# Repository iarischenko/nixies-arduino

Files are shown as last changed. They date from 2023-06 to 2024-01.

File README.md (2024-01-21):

# nixies-arduino
The repository contains sch, pcb and source code files for clock based on
IN12 nixie tubes.
The clock is based on custom stm32 board, MAX1771 boost converter, HV5812 high
voltage drivers, PEC16 encoder and FUSB302 usb pd phy.

## folder structure
freecad-project: case FreeCAD 3d models\
kicad-projects : pcb's KiCAD projects\
software       : libopencm3 based software for stm32 based MCU board

## IN12 v3
(master)
in12 nixie tubes (https://youtu.be/ojTo4SyceIE)

## IN12 v2
see v2 tag
### IN12 v2 (demo, clickable video)
in12 nixie tubes (http://www.youtube.com/watch?v=4i1YHq5AIks)

## IN12 v1
see v1 tag
Prototype photo:


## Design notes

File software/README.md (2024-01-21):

Easy "clone and go" repository for a libopencm3 based project.

# Instructions
 1. git clone --recurse-submodules https://github.com/libopencm3/libopencm3-template.git your-project
 2. cd software
 3. make -C libopencm3 # (Only needed once)
 4. bear --append -- make -C stm32f103-nixie

bear is needed to create compile_commands.json and enable clangd

If you have an older git, or got ahead of yourself and skipped the ```--recurse-submodules```
you can fix things by running ```git submodule update --init``` (This is only needed once)

# Directories
* stm32f103-nixie contains stm32 nixie tubes application

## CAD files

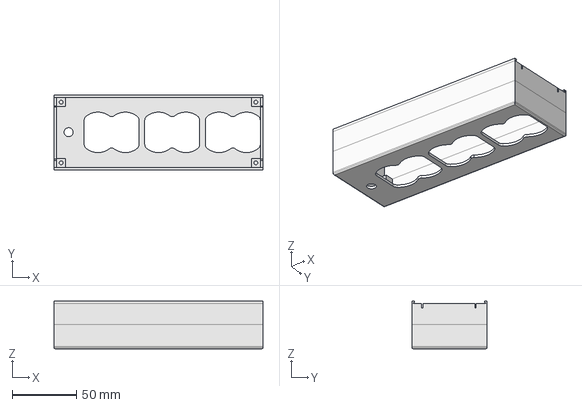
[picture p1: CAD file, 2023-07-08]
freecad-project/case2-Body.step
162.2 x 58.2 x 37.0 mm

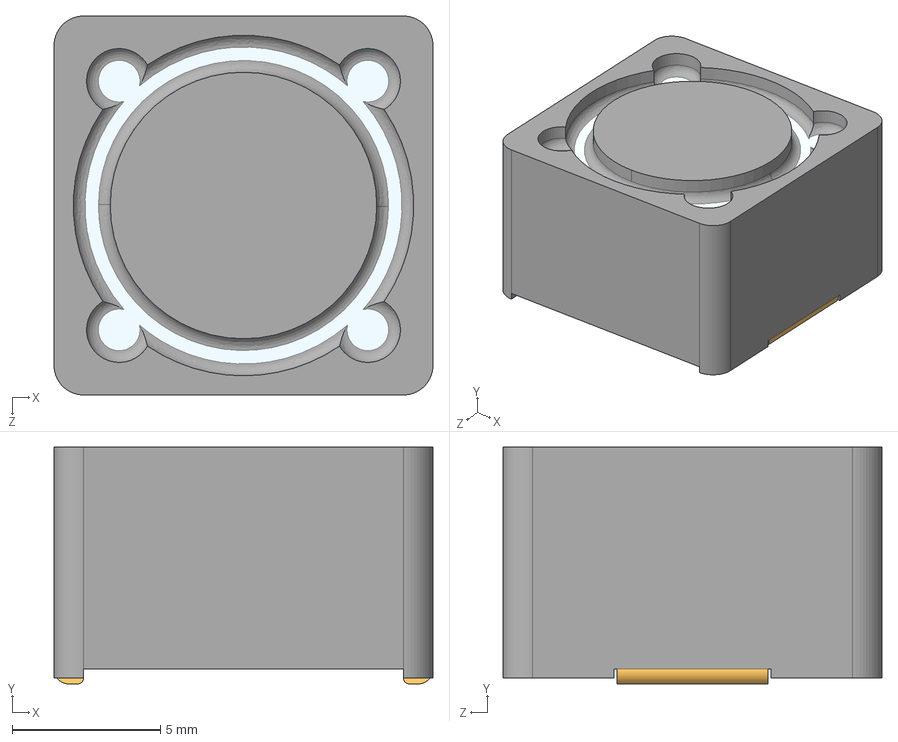
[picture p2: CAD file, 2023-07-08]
kicad-projects/3d_model/User Library-b82477g4.step
12.8 x 8.00 x 12.8 mm

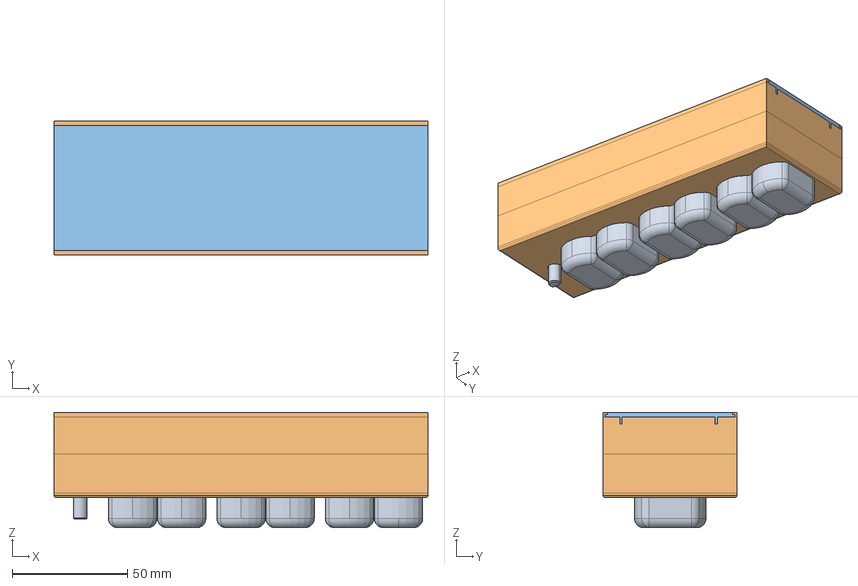
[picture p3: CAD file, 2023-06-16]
freecad-project/case2.FCStd
162.2 x 58.2 x 50.0 mm
clock_top

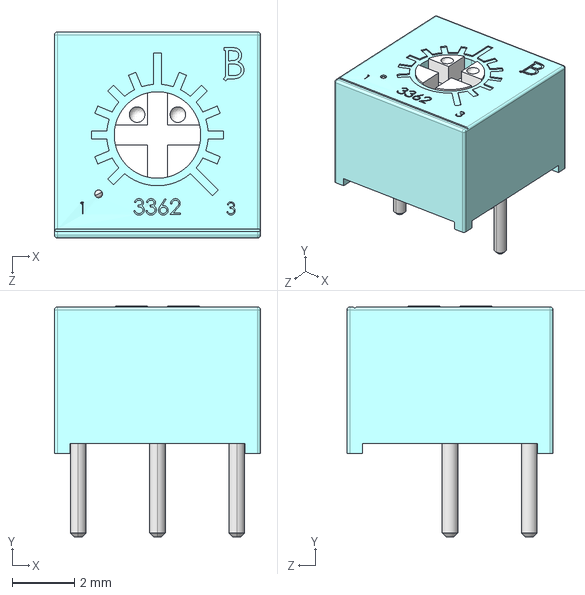
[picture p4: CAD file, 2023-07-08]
kicad-projects/3d_model/User Library-3362P-1-102LF.step
6.60 x 7.40 x 6.60 mm

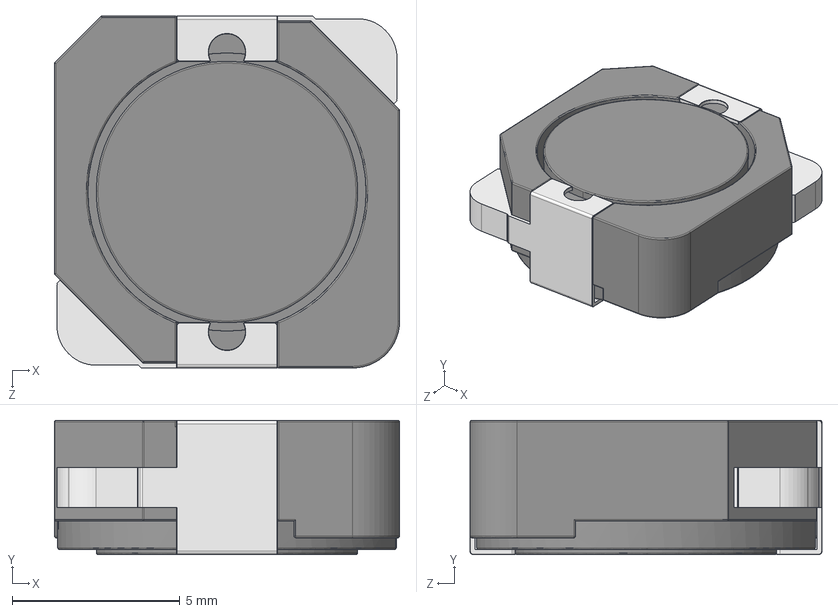
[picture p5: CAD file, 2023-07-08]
kicad-projects/3d_model/User Library-cdrh104r.STEP
10.3 x 4.00 x 10.5 mm
CDRH104R_KORPUS
CDRH104R_NOGKA
CDRH104R_NOGKA_1

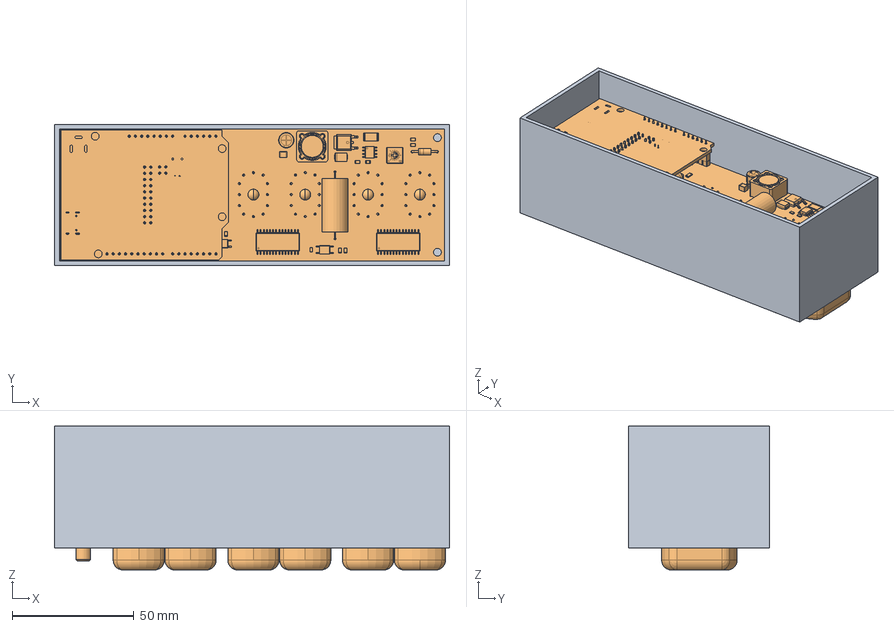
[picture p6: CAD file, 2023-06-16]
freecad-project/case1.FCStd
162.0 x 58.0 x 59.0 mm
clock_top

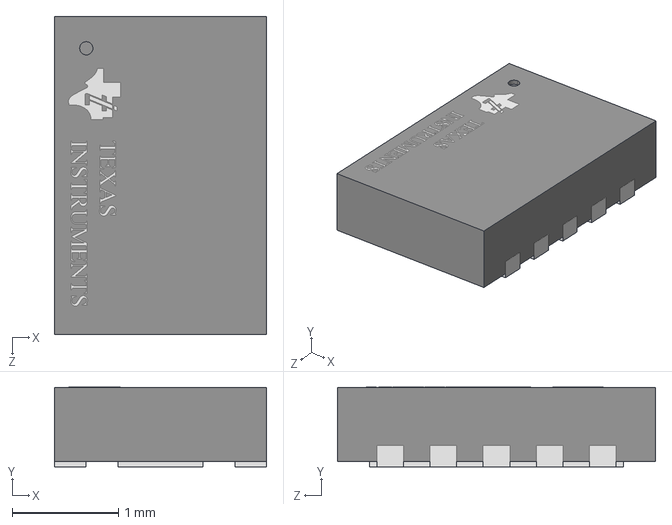
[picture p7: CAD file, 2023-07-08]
kicad-projects/3d_model/User Library-TPS62177DQCT.step
2.00 x 0.75 x 3.00 mm

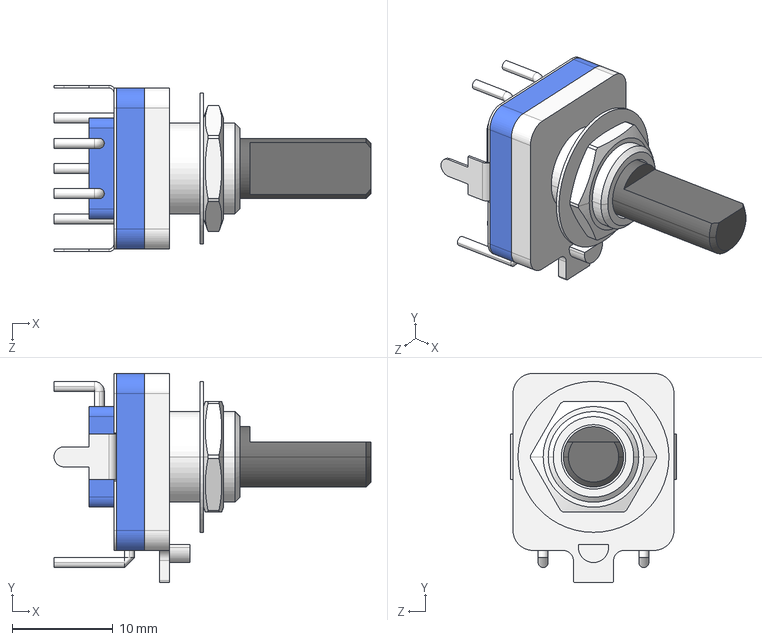
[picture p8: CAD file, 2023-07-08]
kicad-projects/3d_model/User Library-Encoder PEC16-4220F-S0024 BOURNS.step
31.5 x 20.8 x 16.5 mm

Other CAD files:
freecad-project/assemble.FCStd
freecad-project/case2-Body.stl

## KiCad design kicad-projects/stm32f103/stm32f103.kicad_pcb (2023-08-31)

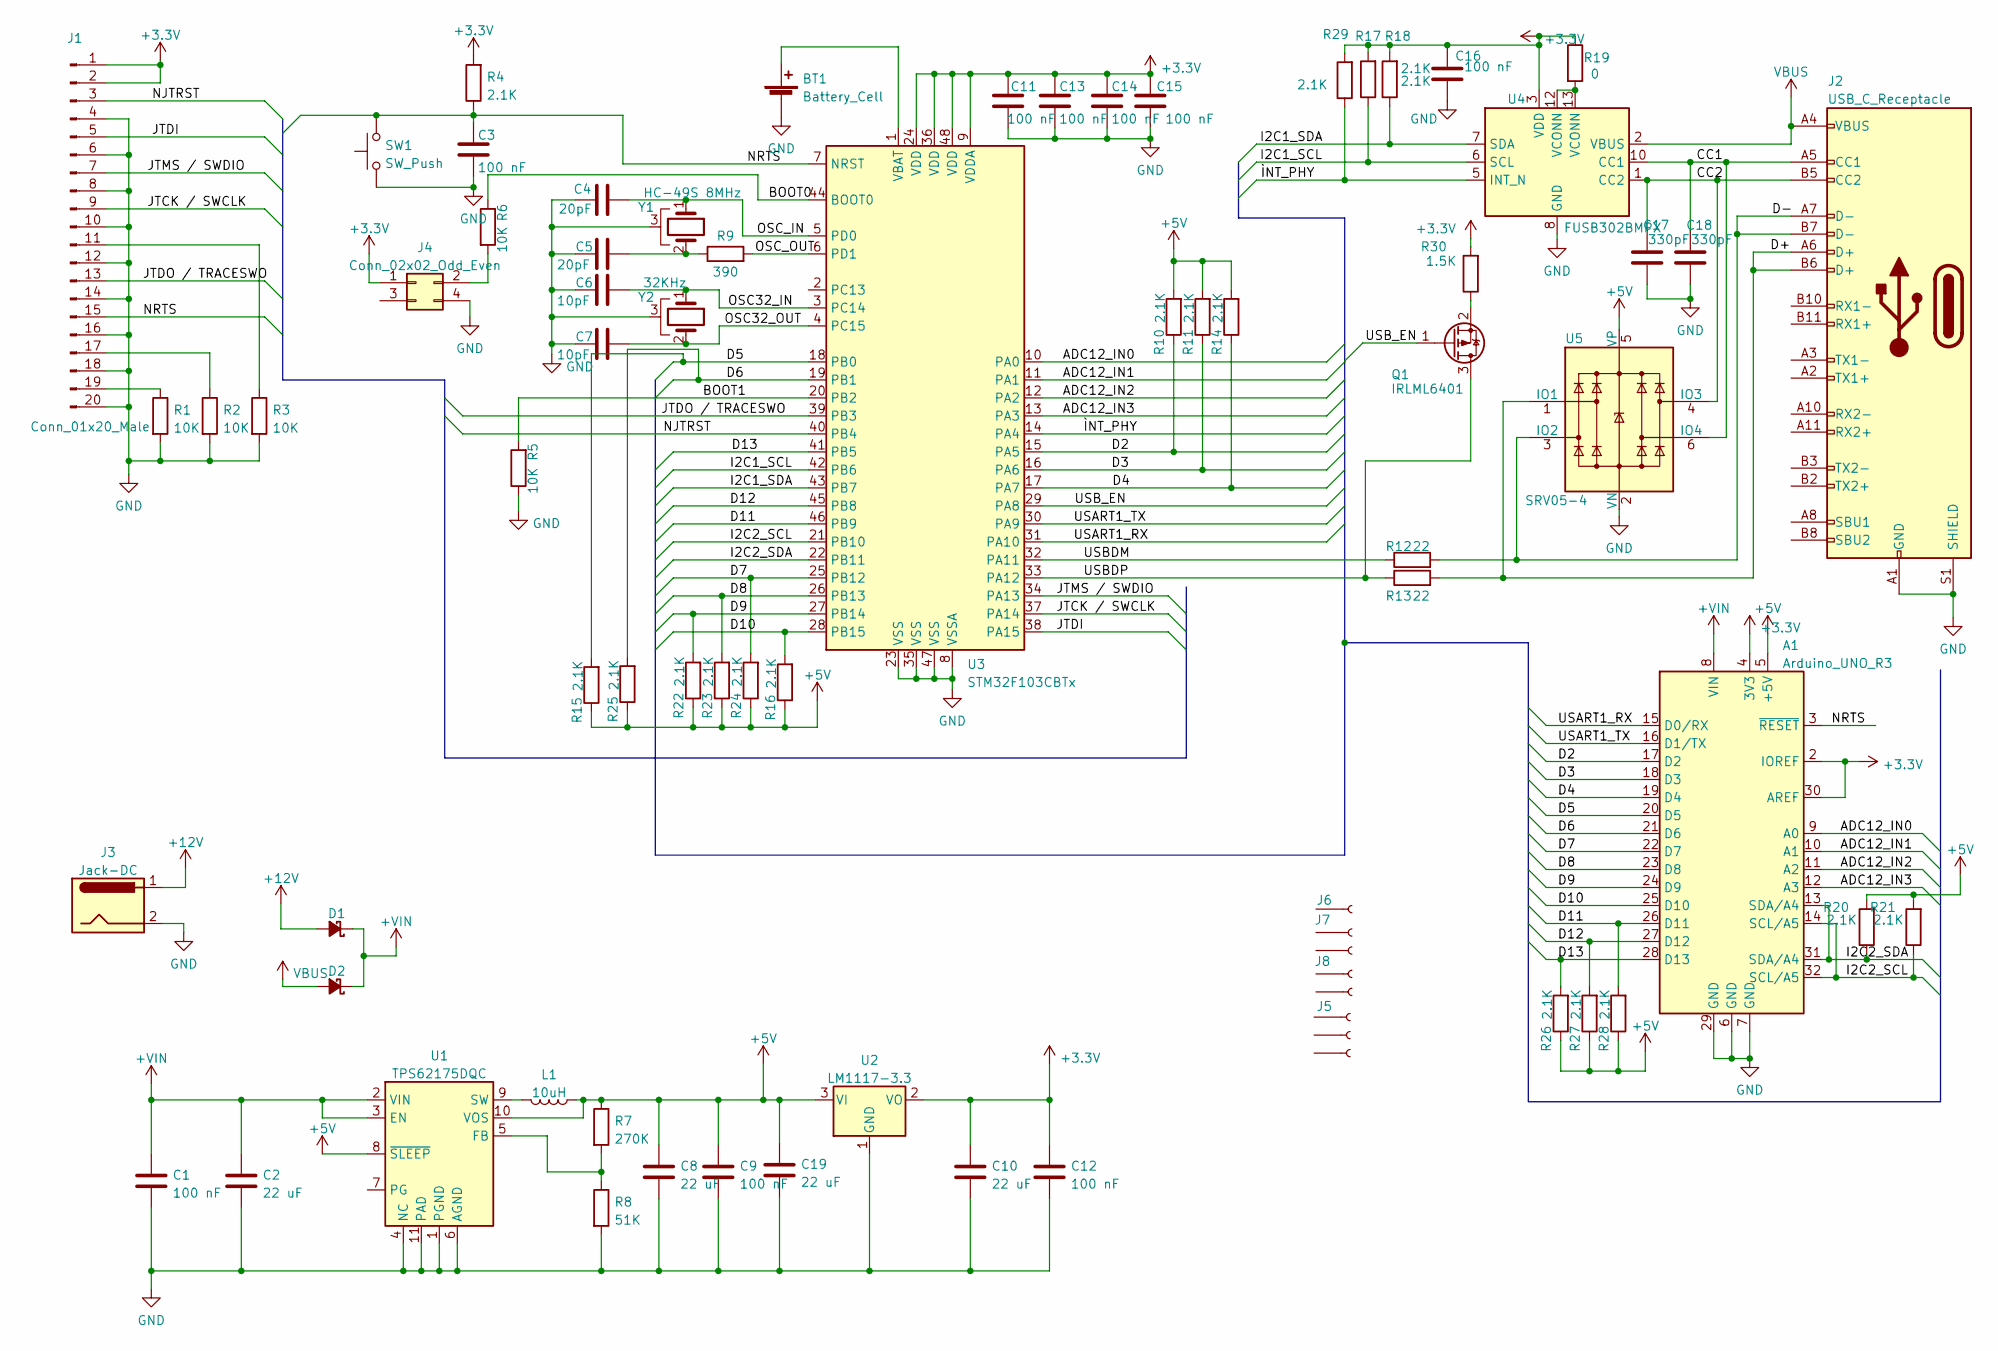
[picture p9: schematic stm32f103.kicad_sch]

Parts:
A1: Arduino_UNO_R3; Arduino_UNO_R3_WithMountingHoles_inverted
BT1: Battery_Cell; BatteryHolder_Keystone_1060_1x2032
C1, C3, C9, C11, C12, C13, C14, C15, C16: 100 nF; C_0805_2012Metric_Pad1.18x1.45mm_HandSolder
C2, C8, C10, C19: 22 uF; C_1206_3216Metric_Pad1.33x1.80mm_HandSolder
C4, C5: 20pF; C_0805_2012Metric_Pad1.18x1.45mm_HandSolder
C6, C7: 10pF; C_0805_2012Metric_Pad1.18x1.45mm_HandSolder
C17, C18: 330pF; C_0805_2012Metric_Pad1.18x1.45mm_HandSolder
D1, D2: D_Schottky_Small_Filled; D_SMA
J1: Conn_01x20_Male; PinHeader_2x10_P2.54mm_Vertical
J2: USB_C_Receptacle; USB_C_Receptacle_HRO_TYPE-C-31-M-12
J3: Jack-DC; BarrelJack_Horizontal
J4: Conn_02x02_Odd_Even; PinHeader_2x02_P2.54mm_Vertical
J5: Conn_01x10_Female; PinSocket_1x10_P2.54mm_Vertical
J6: Conn_01x06_Female; PinSocket_1x06_P2.54mm_Vertical
J7, J8: Conn_01x08_Female; PinSocket_1x08_P2.54mm_Vertical
L1: 10uH; L_Vishay_IHLP-4040
Q1: IRLML6401; SOT-23
R1, R2, R3, R5, R6: 10K; R_0805_2012Metric_Pad1.20x1.40mm_HandSolder
R4, R10, R11, R14, R15, R16, R17, R18, R20, R21, R22, R23, R24, R25, R26, R27, R28, R29: 2.1K; R_0805_2012Metric_Pad1.20x1.40mm_HandSolder
R7: 270K; R_0805_2012Metric_Pad1.20x1.40mm_HandSolder
R8: 51K; R_0805_2012Metric_Pad1.20x1.40mm_HandSolder
R9: 390; R_0805_2012Metric_Pad1.20x1.40mm_HandSolder
R12, R13: 22; R_0805_2012Metric_Pad1.20x1.40mm_HandSolder
R19: 0; R_0805_2012Metric_Pad1.20x1.40mm_HandSolder
R30: 1.5K; R_0805_2012Metric_Pad1.20x1.40mm_HandSolder
SW1: SW_Push; SW_Push_1P1T_NO_CK_KSC7xxJ
U1: TPS62175DQC; WSON-10-1EP_2x3mm_P0.5mm_EP0.84x2.4mm_ThermalVias
U2: LM1117-3.3; SOT-223-3_TabPin2
U3: STM32F103CBTx; LQFP-48_7x7mm_P0.5mm
U4: FUSB302BMPX; WQFN-14-1EP_2.5x2.5mm_P0.5mm_EP1.45x1.45mm
U5: SRV05-4; SOT-23-6
Y1: HC-49S 8MHz; Crystal_SMD_HC49-SD
Y2: 32KHz; Crystal_C38-LF_D3.0mm_L8.0mm_Horizontal_1EP_style2

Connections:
+3.3V: A1.2 (IOREF), A1.4 (3V3), A1.30 (AREF), C10.1, C11.1, C12.1, C13.1, C14.1, C15.1, C16.1, J1.1, J1.2, J4.1, R4.2, R17.2, R18.2, R19.1, R29.2, R30.2, U2.2 (VO), U3.9 (VDDA), U3.24 (VDD), U3.36 (VDD), U3.48 (VDD), U4.3 (VDD), U4.4 (VDD)
+5V: A1.5 (+5V), C8.1, C9.1, C19.1, L1.1, R7.1, R10.2, R11.2, R14.2, R15.1, R16.1, R20.2, R21.2, R22.1, R23.1, R24.1, R25.1, R26.1, R27.1, R28.1, U1.8 (~SLEEP), U1.10 (VOS), U2.3 (VI), U5.5 (VP)
+12V: D1.2 (A), J3.1
+VIN: A1.8 (VIN), C1.1, C2.1, D1.1 (K), D2.1 (K), U1.2 (VIN), U1.3 (EN)
/ADC12_IN0: A1.9 (A0), U3.10 (PA0)
/ADC12_IN1: A1.10 (A1), U3.11 (PA1)
/ADC12_IN2: A1.11 (A2), U3.12 (PA2)
/ADC12_IN3: A1.12 (A3), U3.13 (PA3)
/BOOT0: R6.1, U3.44 (BOOT0)
/BOOT1: R5.2, U3.20 (PB2)
/CC1: C18.2, J2.A5 (CC1), U4.10 (CC1), U4.11 (CC1), U5.6 (IO4)
/CC2: C17.2, J2.B5 (CC2), U4.1 (CC2), U4.14 (CC2), U5.4 (IO3)
/D2: A1.17 (D2), R10.1, U3.15 (PA5)
/D3: A1.18 (D3), R11.1, U3.16 (PA6)
/D4: A1.19 (D4), R14.1, U3.17 (PA7)
/D5: A1.20 (D5), R15.2, U3.18 (PB0)
/D6: A1.21 (D6), R25.2, U3.19 (PB1)
/D7: A1.22 (D7), R24.2, U3.25 (PB12)
/D8: A1.23 (D8), R23.2, U3.26 (PB13)
/D9: A1.24 (D9), R22.2, U3.27 (PB14)
/D10: A1.25 (D10), R16.2, U3.28 (PB15)
/D11: A1.26 (D11), R28.2, U3.46 (PB9)
/D12: A1.27 (D12), R27.2, U3.45 (PB8)
/D13: A1.28 (D13), R26.2, U3.41 (PB5)
/D+: J2.A6 (D+), J2.B6 (D+), R13.2, U5.1 (IO1)
/D-: J2.A7 (D-), J2.B7 (D-), R12.2, U5.3 (IO2)
/I2C1_SCL: R17.1, U3.42 (PB6), U4.6 (SCL)
/I2C1_SDA: R18.1, U3.43 (PB7), U4.7 (SDA)
/I2C2_SCL: A1.14 (SCL/A5), A1.32 (SCL/A5), R21.1, U3.21 (PB10)
/I2C2_SDA: A1.13 (SDA/A4), A1.31 (SDA/A4), R20.1, U3.22 (PB11)
/JTCK / SWCLK: J1.9, U3.37 (PA14)
/JTDI: J1.5, U3.38 (PA15)
/JTDO / TRACESWO: J1.13, U3.39 (PB3)
/JTMS / SWDIO: J1.7, U3.34 (PA13)
/NJTRST: J1.3, U3.40 (PB4)
/NRTS: A1.3 (~RESET), C3.1, J1.15, R4.1, SW1.2, U3.7 (NRST)
/OSC32_IN: C6.2, U3.3 (PC14), Y2.1
/OSC32_OUT: C7.2, U3.4 (PC15), Y2.2
/OSC_IN: C4.2, U3.5 (PD0), Y1.1
/OSC_OUT: R9.2, U3.6 (PD1)
/USART1_RX: A1.15 (D0/RX), U3.31 (PA10)
/USART1_TX: A1.16 (D1/TX), U3.30 (PA9)
/USBDM: R12.1, U3.32 (PA11)
/USBDP: Q1.3 (D), R13.1, U3.33 (PA12)
/USB_EN: Q1.1 (G), U3.29 (PA8)
/ÌNT_PHY: R29.1, U3.14 (PA4), U4.5 (INT_N)
GND: A1.6 (GND), A1.7 (GND), A1.29 (GND), BT1.2 (-), C1.2, C2.2, C3.2, C4.1, C5.1, C6.1, C7.1, C8.2, C9.2, C10.2, C11.2, C12.2, C13.2, C14.2, C15.2, C16.2, C17.1, C18.1, C19.2, J1.4, J1.6, J1.8, J1.10, J1.12, J1.14, J1.16, J1.18, J1.20, J2.A1 (GND), J2.A12 (GND), J2.B1 (GND), J2.B12 (GND), J2.S1 (SHIELD), J3.2, J4.4, R1.2, R2.2, R3.2, R5.1, R8.2, SW1.1, U1.1 (PGND), U1.4 (NC), U1.6 (AGND), U1.11 (PAD), U2.1 (GND), U3.8 (VSSA), U3.23 (VSS), U3.35 (VSS), U3.47 (VSS), U4.8 (GND), U4.9 (GND), U4.15 (GND), U5.2 (VN), Y1.3, Y2.3
unnamed: BT1.1 (+), U3.1 (VBAT)
unnamed: C5.2, R9.1, Y1.2
unnamed: J1.11, R3.1
unnamed: J1.17, R2.1
unnamed: J1.19, R1.1
unnamed: J4.2, R6.2
unnamed: L1.2, U1.9 (SW)
unnamed: Q1.2 (S), R30.1
unnamed: R7.2, R8.1, U1.5 (FB)
unnamed: R19.2, U4.12 (VCONN), U4.13 (VCONN)
VBUS: D2.2 (A), J2.A4 (VBUS), J2.A9 (VBUS), J2.B4 (VBUS), J2.B9 (VBUS), U4.2 (VBUS)

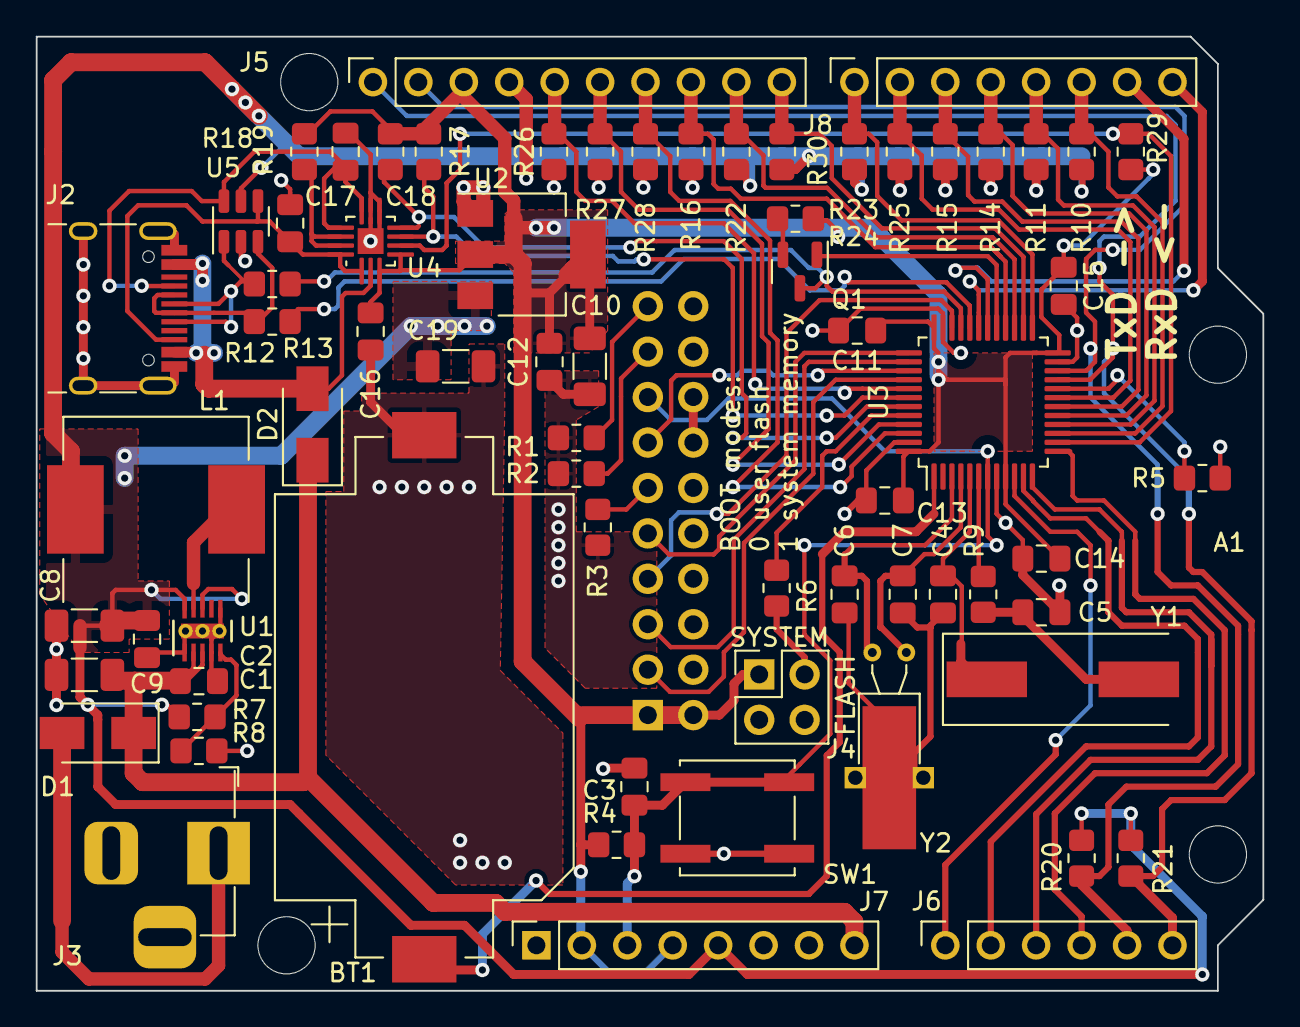
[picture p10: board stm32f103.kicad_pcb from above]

Board: 2 copper layers, 68.6 x 53.3 mm, 71 parts (1 on the bottom side), 58 nets.

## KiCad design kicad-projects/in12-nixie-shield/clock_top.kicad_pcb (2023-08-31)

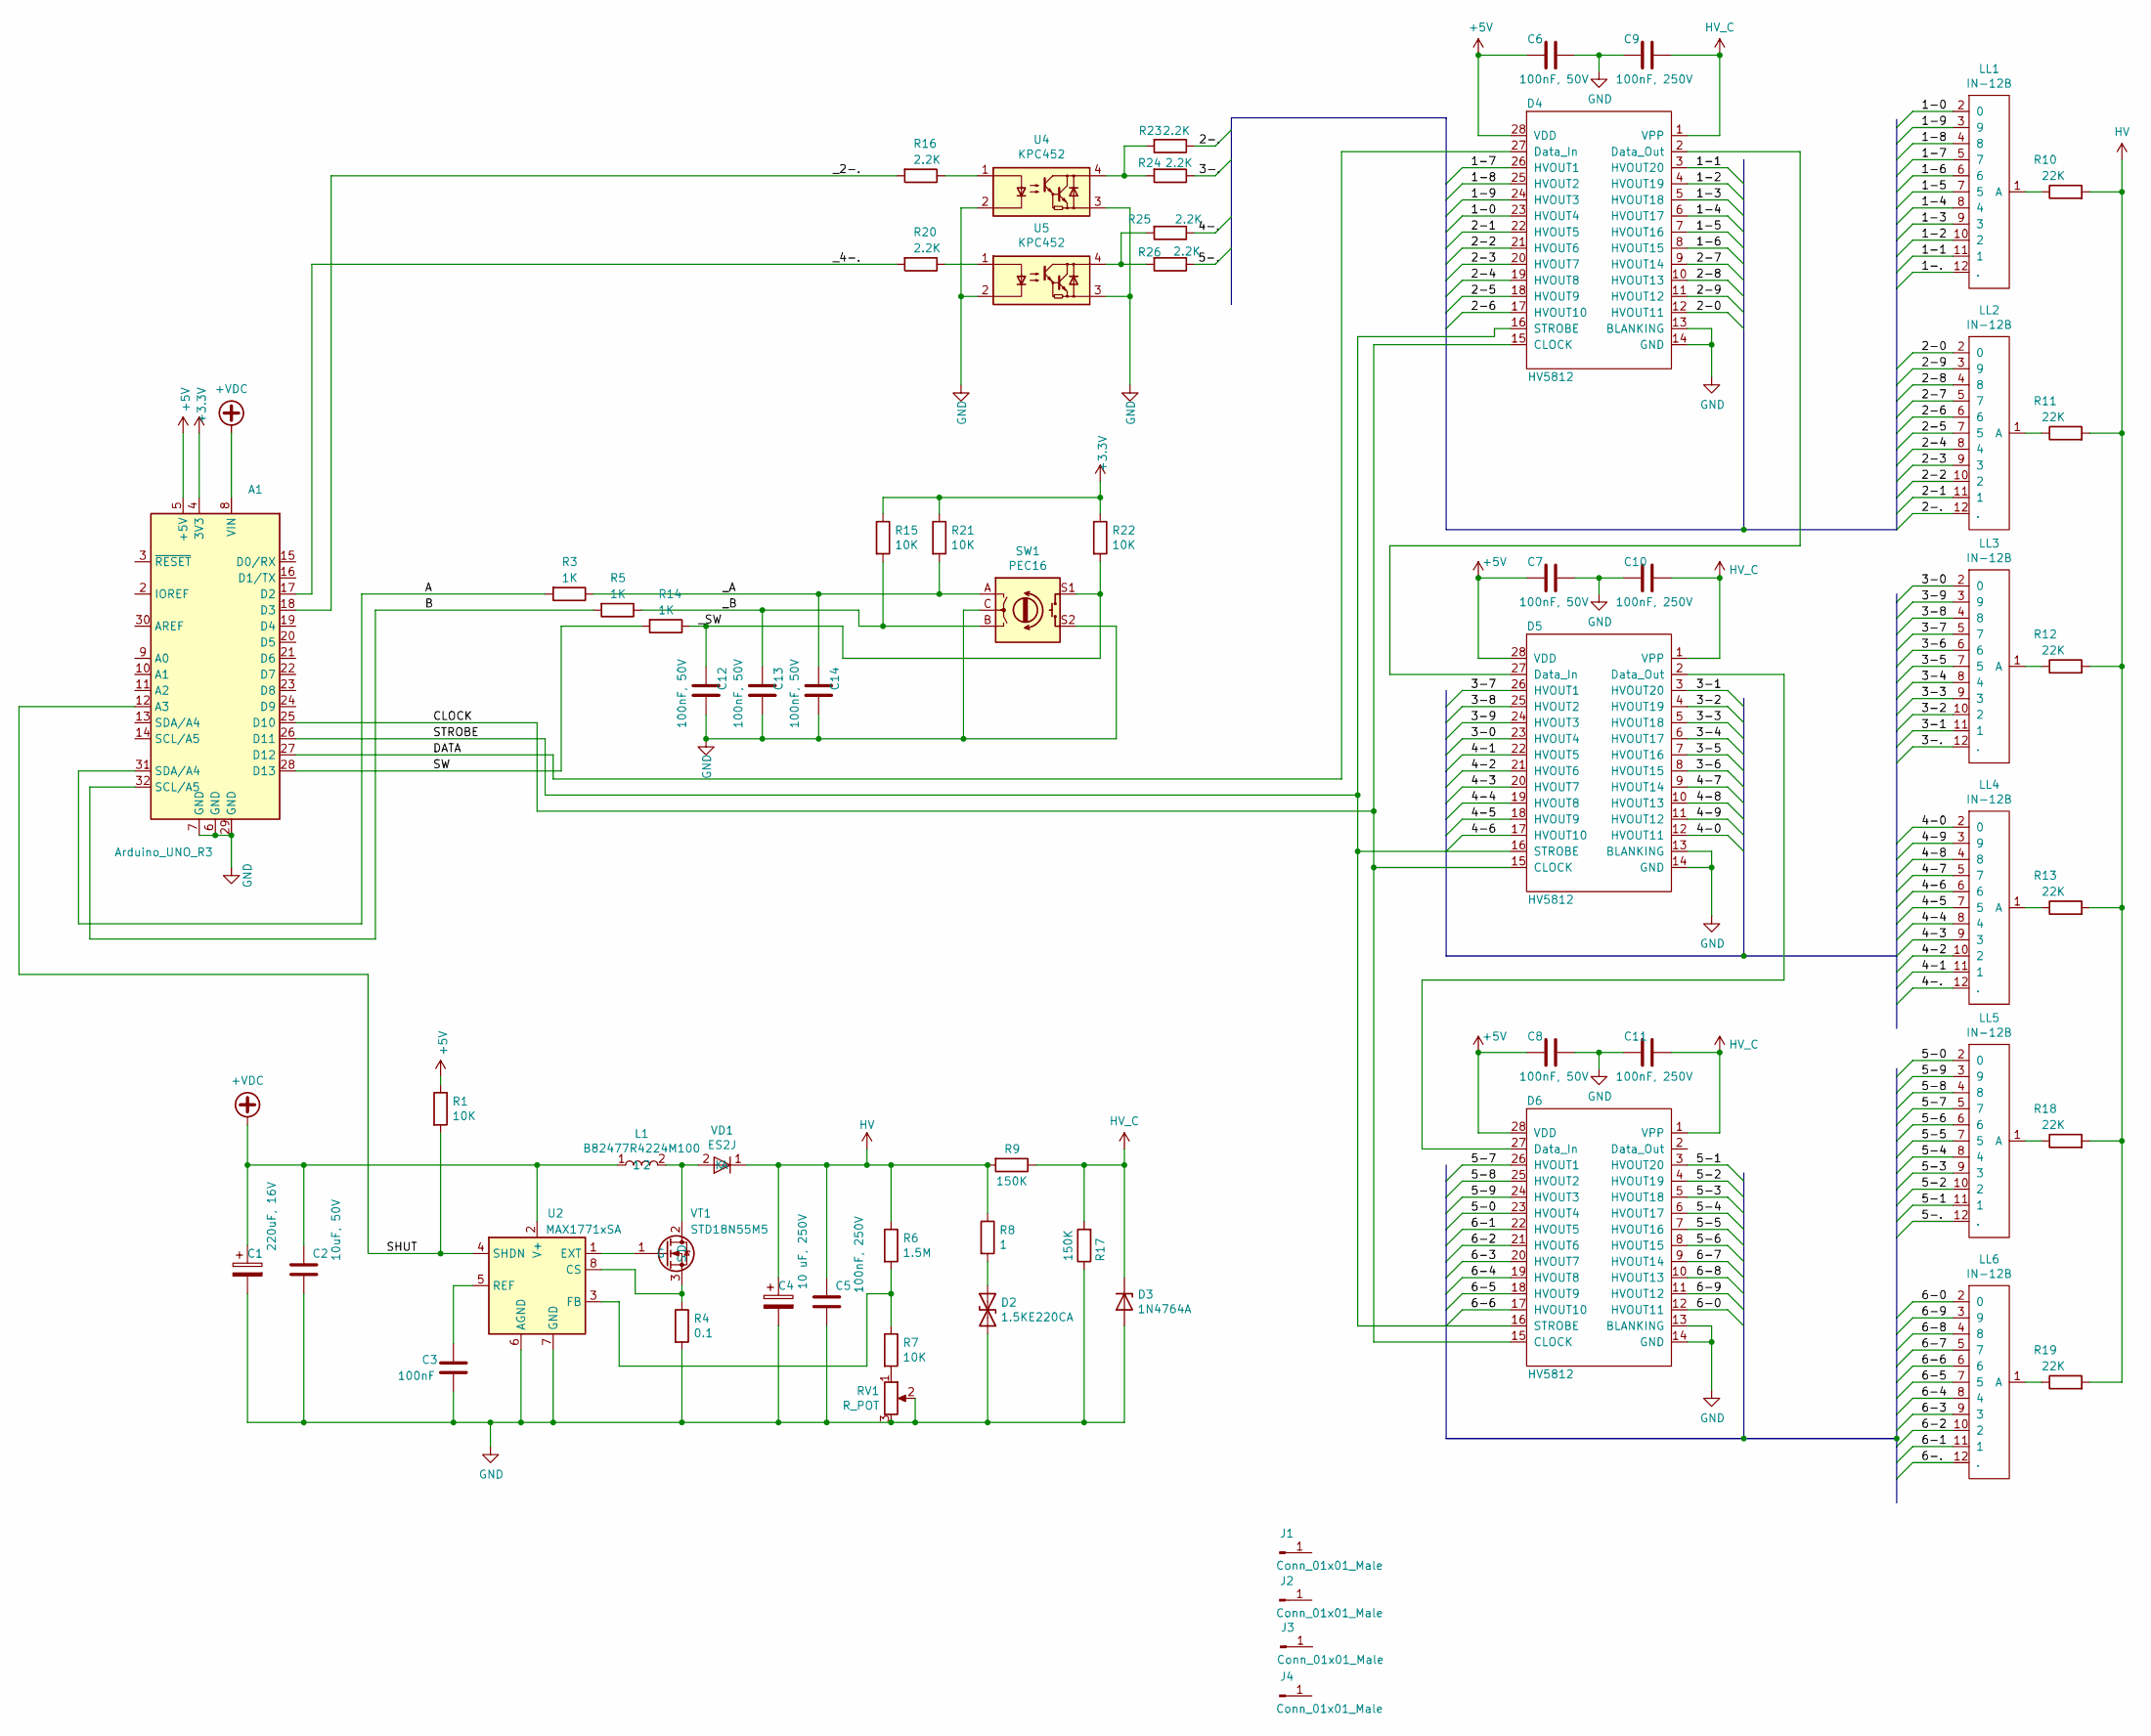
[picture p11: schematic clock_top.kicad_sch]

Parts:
A1: Arduino_UNO_R3
C1: 220uF, 16V; CP_Radial_D6.3mm_P2.50mm
C2: 10uF, 50V; C_1210_3225Metric_Pad1.33x2.70mm_HandSolder
C3: 100nF; C_0805_2012Metric_Pad1.15x1.40mm_HandSolder
C4: 10 uF, 250V; C_Axial_L22.0mm_D10.5mm_P27.50mm_Horizontal
C5, C9, C10: 100nF, 250V; C_1206_3216Metric_Pad1.42x1.75mm_HandSolder
C6, C7, C8: 100nF, 50V; C_0805_2012Metric_Pad1.15x1.40mm_HandSolder
C11: 100nF, 250V; C_1206_3216Metric_Pad1.33x1.80mm_HandSolder
C12, C13, C14: 100nF, 50V; C_0805_2012Metric_Pad1.18x1.45mm_HandSolder
D2: 1.5KE220CA; D_DO-201AE_P15.24mm_Horizontal
D3: 1N4764A; D_DO-41_SOD81_P10.16mm_Horizontal
D4, D5, D6: HV5812; SOIC-28W_7.5x17.9mm_P1.27mm
J1, J4: Conn_01x01_Male; PinHeader_1x08_P2.54mm_Vertical
J2: Conn_01x01_Male; PinHeader_1x06_P2.54mm_Vertical
J3: Conn_01x01_Male; PinHeader_1x10_P2.54mm_Vertical
L1: B82477R4224M100; L_12x12mm_H8mm
LL1, LL2, LL3, LL4, LL5, LL6: IN-12B; IN12-HI_IE
R1, R15, R21, R22: 10K; R_0805_2012Metric_Pad1.20x1.40mm_HandSolder
R3, R5, R14: 1K; R_0805_2012Metric_Pad1.20x1.40mm_HandSolder
R4: 0.1; R_2512_6332Metric_Pad1.40x3.35mm_HandSolder
R6: 1.5M; R_0805_2012Metric_Pad1.20x1.40mm_HandSolder
R7: 10K; R_0805_2012Metric
R8: 1; R_1206_3216Metric_Pad1.30x1.75mm_HandSolder
R9, R17: 150K; R_0805_2012Metric_Pad1.20x1.40mm_HandSolder
R10, R11, R12, R13, R18, R19: 22K; R_0805_2012Metric_Pad1.15x1.40mm_HandSolder
R16, R20, R23, R24, R25, R26: 2.2K; R_0805_2012Metric_Pad1.20x1.40mm_HandSolder
RV1: R_POT; 3362P
SW1: PEC16
U2: MAX1771xSA; SO-8_3.9x4.9mm_P1.27mm
U4, U5: KPC452; SO-4_4.4x3.6mm_P2.54mm
VD1: ES2J; D_SMB_Handsoldering
VT1: STD18N55M5; TO-252-2

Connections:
+3V3: A1.4 (3V3), R15.1, R21.1, R22.1
+5V: A1.5 (+5V), C6.2, C7.2, C8.2, D4.28 (VDD), D5.28 (VDD), D6.28 (VDD), R1.1
+VDC: A1.8 (VIN), C1.1, C2.1, L1.1, U2.2 (V+)
/1-0: D4.23 (HVOUT4), LL1.2 (0)
/1-1: D4.3 (HVOUT20), LL1.11 (1)
/1-2: D4.4 (HVOUT19), LL1.10 (2)
/1-3: D4.5 (HVOUT18), LL1.9 (3)
/1-4: D4.6 (HVOUT17), LL1.8 (4)
/1-5: D4.7 (HVOUT16), LL1.7 (5)
/1-6: D4.8 (HVOUT15), LL1.6
/1-7: D4.26 (HVOUT1), LL1.5 (7)
/1-8: D4.25 (HVOUT2), LL1.4 (8)
/1-9: D4.24 (HVOUT3), LL1.3 (9)
/1-.: LL1.12 (.)
/2-0: D4.12 (HVOUT11), LL2.2 (0)
/2-1: D4.22 (HVOUT5), LL2.11 (1)
/2-2: D4.21 (HVOUT6), LL2.10 (2)
/2-3: D4.20 (HVOUT7), LL2.9 (3)
/2-4: D4.19 (HVOUT8), LL2.8 (4)
/2-5: D4.18 (HVOUT9), LL2.7 (5)
/2-6: D4.17 (HVOUT10), LL2.6
/2-7: D4.9 (HVOUT14), LL2.5 (7)
/2-8: D4.10 (HVOUT13), LL2.4 (8)
/2-9: D4.11 (HVOUT12), LL2.3 (9)
/2-.: LL2.12 (.), R23.1
/3-0: D5.23 (HVOUT4), LL3.2 (0)
/3-1: D5.3 (HVOUT20), LL3.11 (1)
/3-2: D5.4 (HVOUT19), LL3.10 (2)
/3-3: D5.5 (HVOUT18), LL3.9 (3)
/3-4: D5.6 (HVOUT17), LL3.8 (4)
/3-5: D5.7 (HVOUT16), LL3.7 (5)
/3-6: D5.8 (HVOUT15), LL3.6
/3-7: D5.26 (HVOUT1), LL3.5 (7)
/3-8: D5.25 (HVOUT2), LL3.4 (8)
/3-9: D5.24 (HVOUT3), LL3.3 (9)
/3-.: LL3.12 (.), R24.1
/4-0: D5.12 (HVOUT11), LL4.2 (0)
/4-1: D5.22 (HVOUT5), LL4.11 (1)
/4-2: D5.21 (HVOUT6), LL4.10 (2)
/4-3: D5.20 (HVOUT7), LL4.9 (3)
/4-4: D5.19 (HVOUT8), LL4.8 (4)
/4-5: D5.18 (HVOUT9), LL4.7 (5)
/4-6: D5.17 (HVOUT10), LL4.6
/4-7: D5.9 (HVOUT14), LL4.5 (7)
/4-8: D5.10 (HVOUT13), LL4.4 (8)
/4-9: D5.11 (HVOUT12), LL4.3 (9)
/4-.: LL4.12 (.), R25.1
/5-0: D6.23 (HVOUT4), LL5.2 (0)
/5-1: D6.3 (HVOUT20), LL5.11 (1)
/5-2: D6.4 (HVOUT19), LL5.10 (2)
/5-3: D6.5 (HVOUT18), LL5.9 (3)
/5-4: D6.6 (HVOUT17), LL5.8 (4)
/5-5: D6.7 (HVOUT16), LL5.7 (5)
/5-6: D6.8 (HVOUT15), LL5.6
/5-7: D6.26 (HVOUT1), LL5.5 (7)
/5-8: D6.25 (HVOUT2), LL5.4 (8)
/5-9: D6.24 (HVOUT3), LL5.3 (9)
/5-.: LL5.12 (.), R26.1
/6-0: D6.12 (HVOUT11), LL6.2 (0)
/6-1: D6.22 (HVOUT5), LL6.11 (1)
/6-2: D6.21 (HVOUT6), LL6.10 (2)
/6-3: D6.20 (HVOUT7), LL6.9 (3)
/6-4: D6.19 (HVOUT8), LL6.8 (4)
/6-5: D6.18 (HVOUT9), LL6.7 (5)
/6-6: D6.17 (HVOUT10), LL6.6
/6-7: D6.9 (HVOUT14), LL6.5 (7)
/6-8: D6.10 (HVOUT13), LL6.4 (8)
/6-9: D6.11 (HVOUT12), LL6.3 (9)
/6-.: LL6.12 (.)
/A: A1.31 (SDA/A4), R3.2
/B: A1.32 (SCL/A5), R5.2
/CLOCK: A1.25 (D10), D4.15 (CLOCK), D5.15 (CLOCK), D6.15 (CLOCK)
/DATA: A1.27 (D12), D4.27 (Data_In)
/SHUT: A1.12 (A3), R1.2, U2.4 (SHDN)
/STROBE: A1.26 (D11), D4.16 (STROBE), D5.16 (STROBE), D6.16 (STROBE)
/SW: A1.28 (D13), R14.2
/_2-.: A1.18 (D3), R16.2
/_4-.: A1.17 (D2), R20.2
/_A: C14.2, R3.1, R21.2, SW1.A
/_B: C13.2, R5.1, R15.2, SW1.B
/_SW: C12.2, R14.1, R22.2, SW1.S1
GND: A1.6 (GND), A1.7 (GND), A1.29 (GND), C1.2, C2.2, C3.2, C4.2, C5.2, C6.1, C7.1, C8.1, C9.2, C10.2, C11.2, C12.1, C13.1, C14.1, D2.2 (A2), D3.2 (A), D4.13 (BLANKING), D4.14 (GND), D5.13 (BLANKING), D5.14 (GND), D6.13 (BLANKING), D6.14 (GND), R4.2, R17.1, RV1.2, RV1.3, SW1.C, SW1.S2, U2.6 (AGND), U2.7 (GND), U4.2, U4.3, U5.2, U5.3
HV: C4.1, C5.1, R6.1, R8.1, R9.2, R10.2, R11.2, R12.2, R13.2, R18.2, R19.2, VD1.1 (K)
HV_C: C9.1, C10.1, C11.1, D3.1 (K), D4.1 (VPP), D5.1 (VPP), D6.1 (VPP), R9.1, R17.2
unnamed: C3.1, U2.5 (REF)
unnamed: D2.1 (A1), R8.2
unnamed: D4.2 (Data_Out), D5.27 (Data_In)
unnamed: D5.2 (Data_Out), D6.27 (Data_In)
unnamed: L1.2, VD1.2 (A), VT1.2 (D)
unnamed: LL1.1 (A), R10.1
unnamed: LL2.1 (A), R11.1
unnamed: LL3.1 (A), R12.1
unnamed: LL4.1 (A), R13.1
unnamed: LL5.1 (A), R18.1
unnamed: LL6.1 (A), R19.1
unnamed: R4.1, U2.8 (CS), VT1.3 (S)
unnamed: R6.2, R7.1, U2.3 (FB)
unnamed: R7.2, RV1.1
unnamed: R16.1, U4.1
unnamed: R20.1, U5.1
unnamed: R23.2, R24.2, U4.4
unnamed: R25.2, R26.2, U5.4
unnamed: U2.1 (EXT), VT1.1 (G)

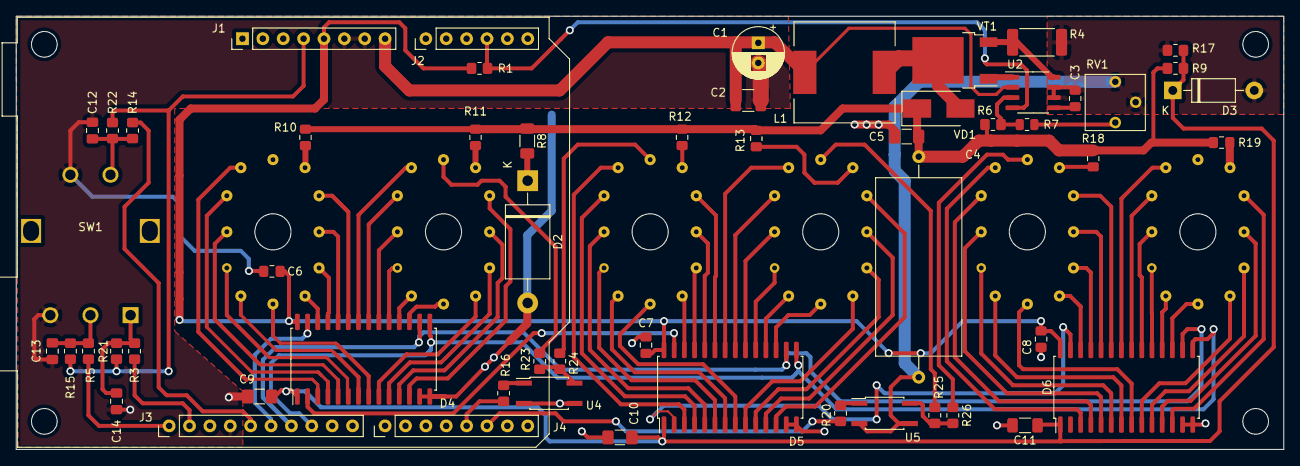
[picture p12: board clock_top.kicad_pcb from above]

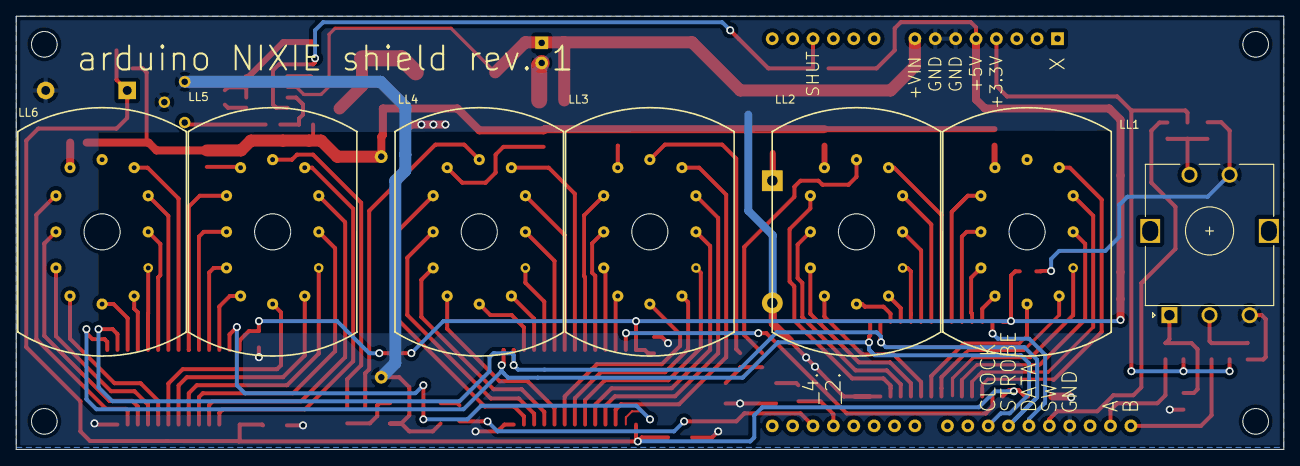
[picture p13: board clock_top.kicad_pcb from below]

Board: 2 copper layers, 158.0 x 54.0 mm, 63 parts (6 on the bottom side), 101 nets.

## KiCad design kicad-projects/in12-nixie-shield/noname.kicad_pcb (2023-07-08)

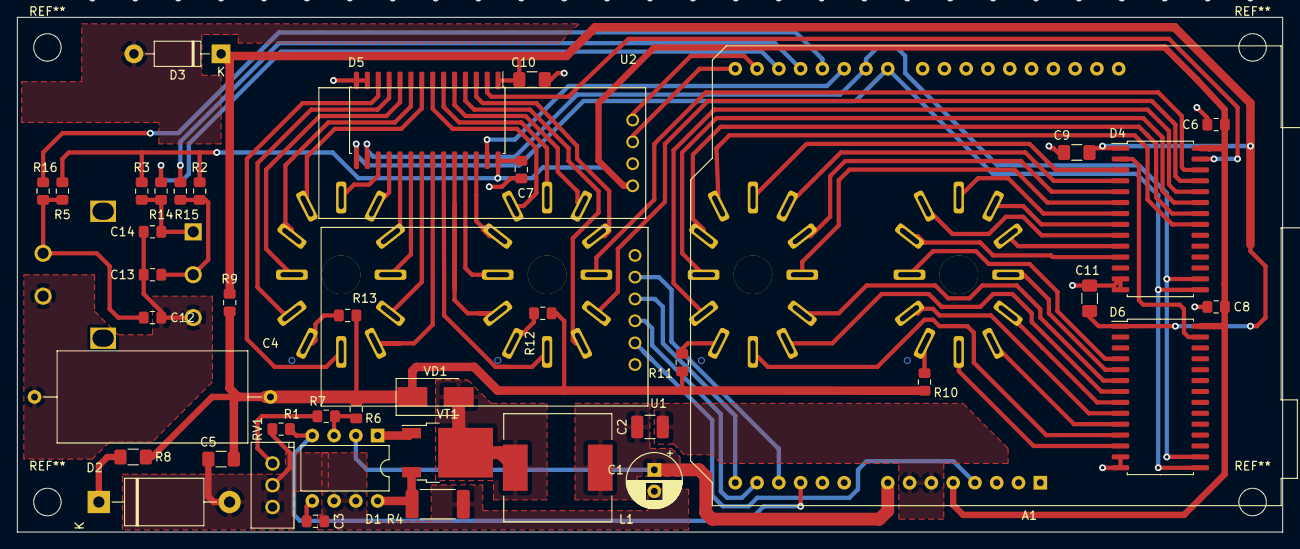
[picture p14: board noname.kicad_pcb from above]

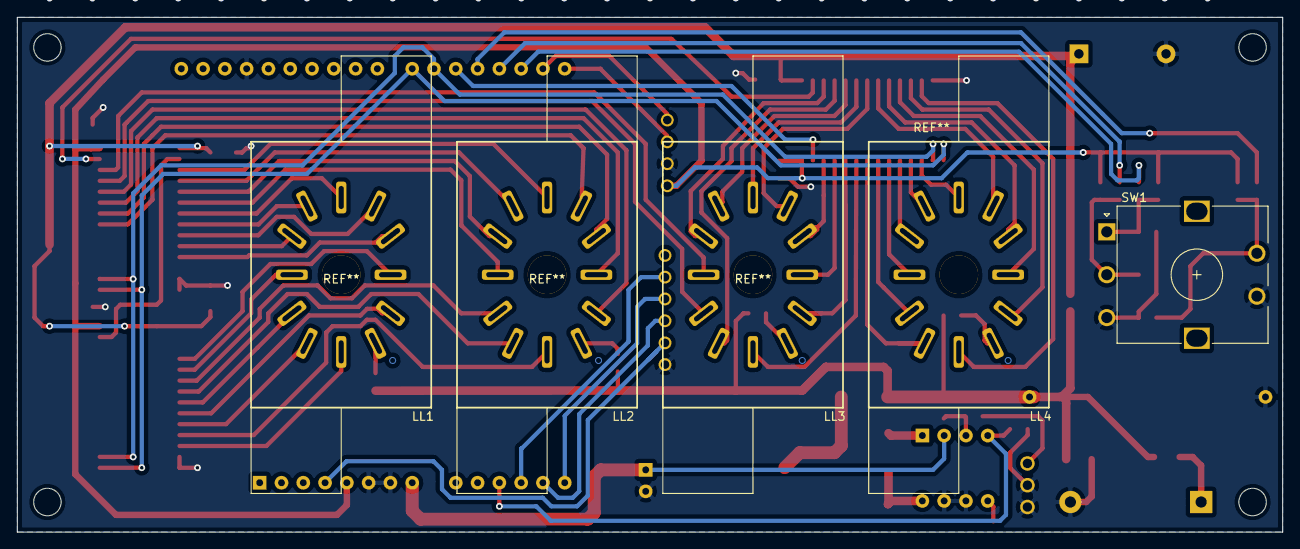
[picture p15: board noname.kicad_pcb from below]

Board: 2 copper layers, 147.5 x 60.0 mm, 48 parts (5 on the bottom side), 78 nets.

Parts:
A1: Arduino_UNO_R3
C1: 220uF, 16V; CP_Radial_D6.3mm_P2.50mm
C2: 10uF, 10V; C_1210_3225Metric_Pad1.42x2.65mm_HandSolder
C3: 100nF; C_0805_2012Metric_Pad1.15x1.40mm_HandSolder
C4: 10 uF, 250V; C_Axial_L22.0mm_D10.5mm_P27.50mm_Horizontal
C5, C9, C10, C11: 100nF, 250V; C_1206_3216Metric_Pad1.42x1.75mm_HandSolder
C6, C7, C8, C12, C13, C14: 100nF, 50V; C_0805_2012Metric_Pad1.15x1.40mm_HandSolder
D1: MAX1771; DIP-8_W7.62mm
D2: 1.5KE220CA; D_DO-201AE_P15.24mm_Horizontal
D3: 1N4764A; D_DO-41_SOD81_P10.16mm_Horizontal
D4, D5, D6: HV5812; SOIC-28W_7.5x17.9mm_P1.27mm
L1: B82477R4224M100; L_12x12mm_H8mm
LL1, LL2, LL3, LL4: IN-12B; PL31
R1, R2, R3, R5, R7: 10K; R_0805_2012Metric_Pad1.15x1.40mm_HandSolder
R4: 0.1; R_2512_6332Metric_Pad1.52x3.35mm_HandSolder
R6: 1.5M; R_0805_2012Metric_Pad1.15x1.40mm_HandSolder
R8: 1; R_1206_3216Metric_Pad1.42x1.75mm_HandSolder
R9: 150K; R_0805_2012Metric_Pad1.15x1.40mm_HandSolder
R10, R11, R12, R13: 22K; R_0805_2012Metric_Pad1.15x1.40mm_HandSolder
R14, R15, R16: 1K; R_0805_2012Metric_Pad1.15x1.40mm_HandSolder
RV1: R_POT; 3296W
SW1: PEC16; RotaryEncoder_Bouruns_PEC16
U1: ZS-042; zs-042
U2: ZS-040; zs-040
VD1: ES2J; D_SMB_Handsoldering
VT1: STD18N55M5; TO-252-2

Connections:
+3V3: A1.4, U1.5
+5V: A1.5, C6.2, C7.2, C8.2, D4.28, D5.28, D6.28, R2.1, R3.1, R5.1, U2.4
+VDC: A1.8, C1.1, C2.1, D1.2, L1.1
/1-0: D6.9, LL1.2
/1-1: D6.10, LL1.11
/1-2: D6.8, LL1.10
/1-3: D6.5, LL1.9
/1-4: D4.10, LL1.8
/1-5: D4.8, LL1.7
/1-6: D4.7, LL1.6
/1-7: D4.9, LL1.5
/1-8: D4.11, LL1.4
/1-9: D6.4, LL1.3
/1-.: D6.12, LL1.12
/2-0: D4.24, LL2.2
/2-1: D6.7, LL2.11
/2-2: D6.6, LL2.10
/2-3: D4.6, LL2.9
/2-4: D4.5, LL2.8
/2-5: D4.4, LL2.7
/2-6: D4.3, LL2.6
/2-7: D4.21, LL2.5
/2-8: D4.22, LL2.4
/2-9: D4.23, LL2.3
/2-.: D6.11, LL2.12
/3-0: D5.24, LL3.2
/3-1: D5.4, LL3.11
/3-2: D4.25, LL3.10
/3-3: D4.26, LL3.9
/3-4: D5.3, LL3.8
/3-5: D5.5, LL3.7
/3-6: D5.6, LL3.6
/3-7: D5.7, LL3.5
/3-8: D5.26, LL3.4
/3-9: D5.25, LL3.3
/3-.: D5.23, LL3.12
/4-0: D5.11, LL4.2
/4-1: D5.22, LL4.11
/4-2: D5.21, LL4.10
/4-3: D5.20, LL4.9
/4-4: D5.19, LL4.8
/4-5: D5.18, LL4.7
/4-6: D5.17, LL4.6
/4-7: D5.8, LL4.5
/4-8: D5.9, LL4.4
/4-9: D5.10, LL4.3
/4-.: D5.12, LL4.12
/A: A1.17, R14.2
/B: A1.18, R15.2
/CLOCK: A1.22, D4.15, D5.15, D6.15
/D-IN-OUT-1-2: D4.2, D6.27
/DATA: A1.20, D5.27
/RT_INT: A1.12, U1.2
/RxD: A1.15, U2.2
/SCL: A1.14, U1.3
/SDA: A1.13, U1.4
/SHUT: A1.11, D1.4, R1.1
/STROBE: A1.21, D4.16, D5.16, D6.16
/SW: A1.19, R16.2
/TxD: A1.16, U2.1
/_A: C14.2, R3.2, R14.1, SW1.A
/_B: C13.2, R2.2, R15.1, SW1.B
/_SW: C12.2, R5.2, R16.1, SW1.S1
GND: A1.6, A1.7, A1.29, C1.2, C2.2, C3.2, C4.2, C5.2, C6.1, C7.1, C8.1, C9.2, C10.2, C11.2, C12.1, C13.1, C14.1, D1.6, D1.7, D2.2, D3.2, D4.13, D4.14, D5.13, D5.14, D6.13, D6.14, R1.2, R4.2, RV1.2, RV1.3, SW1.C, SW1.S2, U1.6, U2.3
HV: C4.1, C5.1, R6.1, R8.1, R9.2, R10.2, R11.2, R12.2, R13.2, VD1.1
HV_C: C9.1, C10.1, C11.1, D3.1, D4.1, D5.1, D6.1, R9.1
unnamed: C3.1, D1.5
unnamed: D1.1, VT1.1
unnamed: D1.3, R6.2, R7.1
unnamed: D1.8, R4.1, VT1.3
unnamed: D2.1, R8.2
unnamed: D4.27, D5.2
unnamed: L1.2, VD1.2, VT1.2
unnamed: LL1.1, R10.1
unnamed: LL2.1, R11.1
unnamed: LL3.1, R12.1
unnamed: LL4.1, R13.1
unnamed: R7.2, RV1.1

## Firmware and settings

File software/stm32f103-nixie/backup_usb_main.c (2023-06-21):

#include <stdlib.h>
#include <libopencm3/stm32/rcc.h>
#include <libopencm3/stm32/gpio.h>
#include <libopencm3/usb/usbd.h>
#include <libopencm3/usb/cdc.h>


#include "api.h"
#include "api-asm.h"

static const struct usb_device_descriptor dev = {
	.bLength = USB_DT_DEVICE_SIZE,
	.bDescriptorType = USB_DT_DEVICE,
	.bcdUSB = 0x0200,
	.bDeviceClass = USB_CLASS_CDC,
	.bDeviceSubClass = 0,
	.bDeviceProtocol = 0,
	.bMaxPacketSize0 = 64,
	.idVendor = 0x0483,
	.idProduct = 0x5740,
	.bcdDevice = 0x0200,
	.iManufacturer = 1,
	.iProduct = 2,
	.iSerialNumber = 3,
	.bNumConfigurations = 1,
};

/*
 * This notification endpoint isn't implemented. According to CDC spec its
 * optional, but its absence causes a NULL pointer dereference in Linux
 * cdc_acm driver.
 */
static const struct usb_endpoint_descriptor comm_endp[] = {{
	.bLength = USB_DT_ENDPOINT_SIZE,
	.bDescriptorType = USB_DT_ENDPOINT,
	.bEndpointAddress = 0x83,
	.bmAttributes = USB_ENDPOINT_ATTR_INTERRUPT,
	.wMaxPacketSize = 16,
	.bInterval = 255,
}};

static const struct usb_endpoint_descriptor data_endp[] = {{
	.bLength = USB_DT_ENDPOINT_SIZE,
	.bDescriptorType = USB_DT_ENDPOINT,
	.bEndpointAddress = 0x01,
	.bmAttributes = USB_ENDPOINT_ATTR_BULK,
	.wMaxPacketSize = 64,
	.bInterval = 1,
}, {
	.bLength = USB_DT_ENDPOINT_SIZE,
	.bDescriptorType = USB_DT_ENDPOINT,
	.bEndpointAddress = 0x82,
	.bmAttributes = USB_ENDPOINT_ATTR_BULK,
	.wMaxPacketSize = 64,
	.bInterval = 1,
}};

static const struct {
	struct usb_cdc_header_descriptor header;
	struct usb_cdc_call_management_descriptor call_mgmt;
	struct usb_cdc_acm_descriptor acm;
	struct usb_cdc_union_descriptor cdc_union;
} __attribute__((packed)) cdcacm_functional_descriptors = {
	.header = {
		.bFunctionLength = sizeof(struct usb_cdc_header_descriptor),
		.bDescriptorType = CS_INTERFACE,
		.bDescriptorSubtype = USB_CDC_TYPE_HEADER,
		.bcdCDC = 0x0110,
	},
	.call_mgmt = {
		.bFunctionLength =
			sizeof(struct usb_cdc_call_management_descriptor),
		.bDescriptorType = CS_INTERFACE,
		.bDescriptorSubtype = USB_CDC_TYPE_CALL_MANAGEMENT,
		.bmCapabilities = 0,
		.bDataInterface = 1,
	},
	.acm = {
		.bFunctionLength = sizeof(struct usb_cdc_acm_descriptor),
		.bDescriptorType = CS_INTERFACE,
		.bDescriptorSubtype = USB_CDC_TYPE_ACM,
		.bmCapabilities = 0,
	},
	.cdc_union = {
		.bFunctionLength = sizeof(struct usb_cdc_union_descriptor),
		.bDescriptorType = CS_INTERFACE,
		.bDescriptorSubtype = USB_CDC_TYPE_UNION,
		.bControlInterface = 0,
		.bSubordinateInterface0 = 1,
	 },
};

static const struct usb_interface_descriptor comm_iface[] = {{
	.bLength = USB_DT_INTERFACE_SIZE,
	.bDescriptorType = USB_DT_INTERFACE,
	.bInterfaceNumber = 0,
	.bAlternateSetting = 0,
	.bNumEndpoints = 1,
	.bInterfaceClass = USB_CLASS_CDC,
	.bInterfaceSubClass = USB_CDC_SUBCLASS_ACM,
	.bInterfaceProtocol = USB_CDC_PROTOCOL_AT,
	.iInterface = 0,

	.endpoint = comm_endp,

	.extra = &cdcacm_functional_descriptors,
	.extralen = sizeof(cdcacm_functional_descriptors),
}};

static const struct usb_interface_descriptor data_iface[] = {{
	.bLength = USB_DT_INTERFACE_SIZE,
	.bDescriptorType = USB_DT_INTERFACE,
	.bInterfaceNumber = 1,
	.bAlternateSetting = 0,
	.bNumEndpoints = 2,
	.bInterfaceClass = USB_CLASS_DATA,
	.bInterfaceSubClass = 0,
	.bInterfaceProtocol = 0,
	.iInterface = 0,

	.endpoint = data_endp,
}};

static const struct usb_interface ifaces[] = {{
	.num_altsetting = 1,
	.altsetting = comm_iface,
}, {
	.num_altsetting = 1,
	.altsetting = data_iface,
}};

static const struct usb_config_descriptor config = {
	.bLength = USB_DT_CONFIGURATION_SIZE,
	.bDescriptorType = USB_DT_CONFIGURATION,
	.wTotalLength = 0,
	.bNumInterfaces = 2,
	.bConfigurationValue = 1,
	.iConfiguration = 0,
	.bmAttributes = 0x80,
	.bMaxPower = 0x32,

	.interface = ifaces,
};

static const char *usb_strings[] = {
	"Black Sphere Technologies",
	"CDC-ACM Demo",
	"DEMO",
};

/* Buffer to be used for control requests. */
uint8_t usbd_control_buffer[128];

static enum usbd_request_return_codes cdcacm_control_request(usbd_device *usbd_dev, struct usb_setup_data *req, uint8_t **buf,
		uint16_t *len, void (**complete)(usbd_device *usbd_dev, struct usb_setup_data *req))
{
	(void)complete;
	(void)buf;
	(void)usbd_dev;

	switch (req->bRequest) {
	case USB_CDC_REQ_SET_CONTROL_LINE_STATE: {
		/*
		 * This Linux cdc_acm driver requires this to be implemented
		 * even though it's optional in the CDC spec, and we don't
		 * advertise it in the ACM functional descriptor.
		 */
		char local_buf[10];
		struct usb_cdc_notification *notif = (void *)local_buf;

		/* We echo signals back to host as notification. */
		notif->bmRequestType = 0xA1;
		notif->bNotification = USB_CDC_NOTIFY_SERIAL_STATE;
		notif->wValue = 0;
		notif->wIndex = 0;
		notif->wLength = 2;
		local_buf[8] = req->wValue & 3;
		local_buf[9] = 0;
		// usbd_ep_write_packet(0x83, buf, 10);
		return USBD_REQ_HANDLED;
		}
	case USB_CDC_REQ_SET_LINE_CODING:
		if (*len < sizeof(struct usb_cdc_line_coding))
			return USBD_REQ_NOTSUPP;
		return USBD_REQ_HANDLED;
	}
	return USBD_REQ_NOTSUPP;
}

static void cdcacm_data_rx_cb(usbd_device *usbd_dev, uint8_t ep)
{
	(void)ep;
	(void)usbd_dev;

	char buf[64];
	int len = usbd_ep_read_packet(usbd_dev, 0x01, buf, 64);

	if (len) {
		usbd_ep_write_packet(usbd_dev, 0x82, buf, len);
	}
}

static void cdcacm_set_config(usbd_device *usbd_dev, uint16_t wValue)
{
	(void)wValue;
	(void)usbd_dev;

	usbd_ep_setup(usbd_dev, 0x01, USB_ENDPOINT_ATTR_BULK, 64, cdcacm_data_rx_cb);
	usbd_ep_setup(usbd_dev, 0x82, USB_ENDPOINT_ATTR_BULK, 64, NULL);
	usbd_ep_setup(usbd_dev, 0x83, USB_ENDPOINT_ATTR_INTERRUPT, 16, NULL);

	usbd_register_control_callback(
				usbd_dev,
				USB_REQ_TYPE_CLASS | USB_REQ_TYPE_INTERFACE,
				USB_REQ_TYPE_TYPE | USB_REQ_TYPE_RECIPIENT,
				cdcacm_control_request);
}


int main(void) {
	/* add your own code
	uint32_t rev = 0xaabbccdd;
	rev = rev_bytes(rev);
	return my_func(rev);
    */

	int i;

	usbd_device *usbd_dev;

	rcc_clock_setup_pll(&rcc_hse_configs[RCC_CLOCK_HSE8_72MHZ]);

	rcc_periph_clock_enable(RCC_GPIOB);

	gpio_set(GPIOB, GPIO5);
	gpio_set_mode(GPIOB, GPIO_MODE_OUTPUT_2_MHZ,
		      GPIO_CNF_OUTPUT_PUSHPULL, GPIO5);

	usbd_dev = usbd_init(&st_usbfs_v1_usb_driver, &dev, &config, usb_strings, 3, usbd_control_buffer, sizeof(usbd_control_buffer));
	usbd_register_set_config_callback(usbd_dev, cdcacm_set_config);

	for (i = 0; i < 0x800000; i++)
		__asm__("nop");

	gpio_clear(GPIOB, GPIO5);
	while (1)
		usbd_poll(usbd_dev);




}

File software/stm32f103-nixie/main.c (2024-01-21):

#include <stdlib.h>
#include <stdio.h>

#include <libopencm3/stm32/rcc.h>
#include <libopencm3/cm3/systick.h>
#include <libopencm3/stm32/gpio.h>

#include <PD_UFP.h>
#include <PD_UFP_Protocol.h>

#include "api.h"
#include "api-asm.h"
#include "system.h"



/* Set up a timer to create 1mS ticks. */
static void systick_setup(void)
{
    /* 72MHz / 8 => 9000000 counts per second. */
    systick_set_clocksource(STK_CSR_CLKSOURCE_AHB_DIV8);
    /* 9000000/9000 = 1000 overflows per second - every 1ms one interrupt */
    /* SysTick interrupt every N clock pulses: set reload to N-1 */
    systick_set_reload(8999);
    systick_interrupt_enable();
    /* Start counting. */
    systick_counter_enable();
}

uint32_t system_millis = 0;
/* Called when systick fires */
void sys_tick_handler(void);
void sys_tick_handler(void)
{
    system_millis++;
}

enum system_state *get_system_state(void)
{
    static enum system_state state = SHOW_CLOCK;
    return &state;
}

static struct tm *get_setup_tm(void)
{
    static struct tm date = { 0 };
    return &date;
}

void adjust_number(int i)
{
    struct tm *date = get_setup_tm();
    enum system_state *state = get_system_state();

    if ((*state) == SHOW_CLOCK)
    {
        return;
    }

    if ((*state) == SHOW_DIM_SEC)
    {
        if (i > 0 && date->tm_sec == 59)
        {
            date->tm_sec = 0;
        }
        else if (i < 0 && date->tm_sec == 0)
        {
            date->tm_sec = 59;
        }
        else
            date->tm_sec = date->tm_sec + i;
    }
    else if ((*state) == SHOW_DIM_MIN)
    {
        if (i > 0 && date->tm_min == 59)
        {
            date->tm_min = 0;
        }
        else if (i < 0 && date->tm_min == 0)
        {
            date->tm_min = 59;
        }
        else
            date->tm_min = date->tm_min + i;
    }
    else 
    {
        if (i > 0 && date->tm_hour == 23)
        {
            date->tm_hour = 0;
        }
        else if (i < 0 && date->tm_hour == 0)
        {
            date->tm_hour = 23;
        }
        else
            date->tm_hour = date->tm_hour + i;
    }
}

void step_to_next_state(void)
{
    enum system_state *state = get_system_state();
    struct tm *date = get_setup_tm();

    if (*state == SHOW_CLOCK)
    {
        get_system_time(date);
        *state = SHOW_DIM_SEC;
    }
    else if (*state >= SHOW_DIM_HOUR)
    {
        *state = SHOW_CLOCK;
        set_system_time(date);
    }
    else
    {
        enum system_state st = *state;
        st++;
        *state = st;
    }
}

#define CONVERT(a) a.tm_sec % 10, a.tm_sec / 10,\
                   a.tm_min % 10, a.tm_min / 10,\
                   a.tm_hour %10, a.tm_hour/ 10


#define CONVERTP(a) a->tm_sec % 10, a->tm_sec / 10,\
                   a->tm_min % 10, a->tm_min / 10,\
                   a->tm_hour %10, a->tm_hour/ 10


static void update_system_state(void )
{
    struct tm date = { 0 };
    enum system_state *state = get_system_state();
    static int prev_sec = 0;

    get_system_time(&date);
    if (prev_sec != date.tm_sec && *state == SHOW_CLOCK)
    {
        prev_sec = date.tm_sec;
        if (date.tm_sec == 0)
        {
            tubes_refresh();
        }
        set_tubes(CONVERT(date));
    }
    else if (*state != SHOW_CLOCK)
    {
        struct tm *pdate = get_setup_tm();
        set_tubes(CONVERTP(pdate));
    }
}

int main(void) {
    int power_good = 0;
    int i = 0;
    struct usb_pd_pps context = {};
    volatile int wait = 0;

    /* debug wait for connection */
    while (wait)
    {
        for (i = 0; i < 0x8000; i++)
            __asm__("nop");
    }

    /* clock */
    rcc_clock_setup_pll(&rcc_hse_configs[RCC_CLOCK_HSE8_72MHZ]);
    /* millis */
    systick_setup();
    /* logs */
    usart1_setup();
    /* setup pec16 */
    setup_pec16();
    /* rtc */
    setup_rtc();
    /* */
    setup_tubes();

    /* max1771 enable : gnd - enable  | >1.5V enable  */
    /* PA3 */
    gpio_set_mode(GPIOA, GPIO_MODE_OUTPUT_2_MHZ, GPIO_CNF_OUTPUT_PUSHPULL, GPIO3);
    gpio_set(GPIOA, GPIO3);

    PD_init(&context, PD_POWER_OPTION_MAX_12V);
    //PD_init_PPS(&context, PPS_V(9.0), PPS_A(1), PD_POWER_OPTION_MAX_15V);

    while (1) {
        static uint32_t power_bad = 0;
        PD_run(&context);

        if (context.status_initialized)
        {   /* voltage must be 9V or higher */
            if (context.ready_voltage >=  9 * 20 /*(int )PD_V(9.0) */)
            {
                power_good  = 1;
            }
            else
            {
                power_good = 0; 
            }
        }

        if (power_good)
        {
            gpio_clear(GPIOA, GPIO3);
        } else {
            gpio_set(GPIOA, GPIO3);
            if (power_bad == 0)
            {
                power_bad = system_millis;
            }

            if (system_millis > (power_bad + 1000))
            {
                /* one sec with out power */
                power_bad = 0;
                PD_init(&context, PD_POWER_OPTION_MAX_12V);
                //PD_init_PPS(&context, PPS_V(9.0), PPS_A(1), PD_POWER_OPTION_MAX_15V);
            }
        }

        if (power_good)
        {
            update_system_state();
        }
    }

}

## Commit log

2020-03-16 Arduino sketch: initial version
    The sketch does the following:
    - shows current time and date over nixies tubes: 4 digits and
    4 dots
    - allows to change mode by encoder: show year, day-month,
    hours-minuties, minuties-seconds
    - allows to setup time with encoder for selected mode
    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
2020-03-16 shematic: nixies board
    The board consists of:
    - 4 IN12B nixies tubes
    - PEC16 encoder
    - MAX1771 boots converter
    - connection for Arduino UNO R3 board
    - connection for ZS-042 RTC board
    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
2020-03-16 Panelized nixies PCB
    Top and bottom CU layers.
2020-03-16 README.md is created
    known issues with pcb board are noted
2020-06-07 nixie-in12-arduino.ino is moved to nixie-in12-arduino folder
2020-06-07 z570m arduino shield sch
2020-06-07 sketch for z570m sheild
    Is is a copy of sketch for IN12 tubes.
2020-06-08 fixed configuration for tubes 1,2,3 and 4
2020-06-09 arduino - z570m nixies tubes
    The shield has 6 nixies tubes. The tubes are used to
    show calenar in format year-moth-day or date in format
    hours-minities-seconds. On board PEC16 encoder is used
    to switch from calendar to date and back. The PEC16 button
    is used to setup calendar or adjust date.
2020-07-09 arduino - IN12 nixies tubes
    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
2020-07-19 digits shift
    In order to prevent tubes catones poisoning need to time to time light up
    all digits. Show digits from 0 till 9 looks ugly, digits show order is
    changed from fixed to random.
    Before commit:
    .....
    111111
    222222
    333333
    ....
    After commit:
    ....
    134234
    322451
    ....
2020-10-03 Kicad sch and pcb files
    for IN12v1, IN12v and z570m nixie tubes
    [clock_top.kicad_pcb, clock_top.sch, noname.kicad_pcb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]
2023-06-16 Added: in12 v3 version
    - arduino boards is replaced with stm32 based board
    - shield is updated: more space beetween tubes, unused parts
    are removed (in progress)
    - created case 3d model (in progress)
    [User Library-3362P-1-102LF.step, User Library-Encoder PEC16-4220F-S0024 BOURNS.step, User Library-TPS62177DQCT.step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]
2023-06-21 stm32: initial code
    - fusb302: sanity check: read DEVICE_ID reg
    - stm32 cdc: sanity check: usb-cdc echo example
2023-06-27 FUSB302: import PD_Micro code
    https://github.com/ryan-ma/PD_Micro
    The code will be ported for stm32 target.
2023-07-07 FUSB302: communication with PS works
    log example:
    6:FUSB302 ver ID:B_revB
    9:USB attached CC2 vRd-3.0
    104:RX Src_Cap id=0 raw=0x41A1
    105:obj0=0x0a11912c
    105:obj1=0x0012d12c
    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
2023-07-08 FUSB302: logs fixed
    PS power options log is fixed:
    9:USB attached CC1 vRd-3.0
    158:RX Src_Cap id=0 raw=0x71A1
    158:obj0=0x0801912c
    158:obj1=0x0002d12c
    158:obj2=0x0003c12c
    158:obj3=0x0004b12c
    159:obj4=0x00064145
    159:obj5=0xc0dc213c
    159:obj6=0xc1a4213c
    159:[0] 5.00V3.00A
    159:[1] 9.00V3.00A
    159:[2] 12.00V3.00A
    160:[3] 15.00V3.00A
    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
    [PD_UFP.c]
2023-07-08 z570 is moved to z570 branch
    [clock_top.kicad_pcb, clock_top.sch, noname.kicad_pcb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]
2023-07-08 git repo refactor: rm all
    [User Library-3362P-1-102LF.step, User Library-Encoder PEC16-4220F-S0024 BOURNS.step, User Library-TPS62177DQCT.step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]
2023-07-08 git repo refactor: v1 (in12, arduino 4 tubes)
    [clock_top.kicad_pcb, clock_top.sch, noname.kicad_pcb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]
2023-07-08 git repo refactor: v2 in12, 6 tubes, arduino
    [clock_top.kicad_pcb, clock_top.sch]
2023-07-08 git repo refactor: v3 6 tubes, stm32
    [User Library-3362P-1-102LF.step, User Library-Encoder PEC16-4220F-S0024 BOURNS.step, User Library-TPS62177DQCT.step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]
2023-07-11 stm32: rtc sanity check
    print to uart current date with ctime() function.
2023-08-31 pcb: revision bump
    stm32f103: revison 2
    - added: D+ to +5V (fixed error: unable to enumerate device)
    - added: usb phy int pin pull up to +3.3v (fixed no irq from phy)
    - moved: JTAG connector is moved to bottom layer
    clock-top (nixie shild): revision 1, initial version
    removed pf-info-cache (temp kicad file)
    [clock_top.kicad_pcb, clock_top.kicad_sch, stm32f103.kicad_pcb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]
2023-10-18 stm32: nixie tubes & pec16
    Initial implementation for nixie tubes (hv5812) and pec16 encoder.
2023-11-05 nixie case: free cad project
    1 - main case
    2 - back cover
    It tooks around 100ml of photopolymer resin to print out the case.
    You will need 4 3x40 screw to assemble pcb with main case.
    Main case and back cover are connected with a latch.
2023-11-10 stm32 nixie clock
    - press pec16 button to setup clock
    - rtc calibration value is set in the Makefile
    - stop condition hack: recover i2c module after reset
    - operation votage 9~12 volts
    - nixie tubes: show digits, refresh
    [PD_UFP.c, main.c, nixie-tubes.c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]
